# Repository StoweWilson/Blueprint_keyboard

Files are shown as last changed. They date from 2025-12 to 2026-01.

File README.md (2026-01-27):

## What my project is 
My project is a 64% keyboard designed to resemble the layout of an Apple Magic Keyboard, with a few keys rearranged on either side of the PCB. There will be two magnetic pogo pins on either side, which will allow the keypad with identical pogo pins to connect, as well as allowing the keypad to be placed on either side of the keyboard, therefore making it modular. The case takes inspiration from the Worklouder XYZ Work Board.

## Why I made the project
I really like low-profile 60%–65% keyboards but had trouble finding ones that fit my needs. Learning that I had to put my own spin on the idea, I decided to take on the challenge of adding a keypad while keeping it modular, so I could still have the compactness of a 64% keyboard with the ability to have a numpad that does not make it bulky.

## Images

### Keyboard
keyboard sch
Screenshot 2026-01-01 at 11 01 54 PM
Screenshot 2026-01-26 at 7 12 31 PM

### Keypad
keypad pcb
Screenshot 2026-01-01 at 11 03 55 PM
Screenshot 2026-01-26 at 7 13 42 PM

### Render



## BOM
### Keyboard

|Product name|Product Description|Qty|Price|Product Link|
|---|---|---|-----|---|
|ATmega32U4-A|AVR AVR® ATmega Microcontroller IC 8-Bit 16MHz 32KB (16K x 16) FLASH 44-TQFP (10x10)|1|5.29|https://www.digikey.com/en/products/detail/microchip-technology/ATMEGA32U4-AU/1914602|
|16 MHz Crystal|CRYSTAL 3225 16MHZ 20PF 10PPM|1|.18|https://www.digikey.com/en/products/detail/eaton-electronics-division/E3X160201Y08/25656418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|
|USB6B1 ESD Protector|TVS DIODE 5.25VWM 8SOIC|1|.69|https://www.digikey.com/en/products/detail/stmicroelectronics/USB6B1RL/654663|https://www.digikey.com/en/products/detail/amphenol-icc-fci-/10171746-00021LF/24366718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|
|USB-C Receptacle (USB 2.0)|USB C RECEPTACLE R/A SMT 16P G/F|1|.72|https://www.digikey.com/en/products/detail/amphenol-icc-fci-/10171746-00021LF/24366718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|
|10 kΩ|RES 10 OHM 1% 1/8W 0805|2|.11|https://www.digikey.com/en/products/detail/yageo/RC0805FR-1310RL/13694343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|
|22 Ω|RES 22 OHM 1% 1/8W 0805|2|.11|https://www.digikey.com/en/products/detail/yageo/RC0805FR-1322RL/13694339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|
|5.1 kΩ|RES 5.1K OHM 5% 1/8W 0805|2|.10|https://www.digikey.com/en/products/detail/yageo/RC0805JR-075K1L/728338|
|22 pF|22 pF ±5% 50V Ceramic Capacitor C0G, NP0 0603 (1608 Metric)|2|.12|https://www.digikey.com/en/products/detail/kemet/C0603C220J5GACTU/411055|
|1 µF|CAP CER 1UF 6.3V X5R 0402|1|.08|https://www.digikey.com/en/products/detail/samsung-electro-mechanics/CL05A104KA5NNNC/3886701|
|.1uF|0.1 µF ±10% 25V Ceramic Capacitor X5R 0402 (1005 Metric)|4|.08|https://www.digikey.com/en/products/detail/samsung-electro-mechanics/CL05A104KA5NNNC/3886701|
|Diode|DIODE STANDARD 100V 150MA SOD123|64|.11|https://www.digikey.com/en/products/detail/diodes-incorporated/1N4148W-7-F/814371|
|Reset Button|SWITCH TACTILE SPST-NO 0.05A 12V|1|.41|https://www.digikey.ca/en/products/detail/c-k/Y97KT23B2NAFP/9649861|
|Adafruit 5413 Magnetic Connector|four 0.1" spaced contact pogo pins and a right angl|4|2.13|https://www.aliexpress.us/p/shoppingcart/index.html?spm=a2g0o.detail.0.0.2397nvtbnvtbTw|

### Keypad
|Product name|Product Description|Qty|Price|Product Link|
|---|---|---|-----|---|
|XIAO RP2040 SMD|XIAO RP2040 SMD|1|4.68|https://www.digikey.com/en/products/detail/seeed-technology-co-ltd/102010428/14672129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|
|PCF8575DBR I/O Expander|IC XPNDR 400KHZ I2C SMBUS 24SSOP|1|3.58|https://www.digikey.com/en/products/detail/texas-instruments/PCF8575DBR/754551|
|10 kΩ|RES 10 OHM 1% 1/8W 0805|4|.11|https://www.digikey.com/en/products/detail/yageo/RC0805FR-1310RL/13694343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|
|5.1 kΩ|RES 5.1K OHM 5% 1/8W 0805|2|.10|https://www.digikey.com/en/products/detail/yageo/RC0805JR-075K1L/728338|
|Diode|DIODE STANDARD 100V 150MA SOD123|21|.11|https://www.digikey.com/en/products/detail/diodes-incorporated/1N4148W-7-F/814371|
|Adafruit 5413 Magnetic Connector|four 0.1" spaced contact pogo pins and a right angl|4|2.13|https://www.aliexpress.us/p/shoppingcart/index.html?spm=a2g0o.detail.0.0.2397nvtbnvtbTw|

### Notes
- Shipping is not included in any of the prices.
- PCB with shippiing is $59.04 Qty of 5 each can't change.
- I will pay for the keyboard switches with my own money.

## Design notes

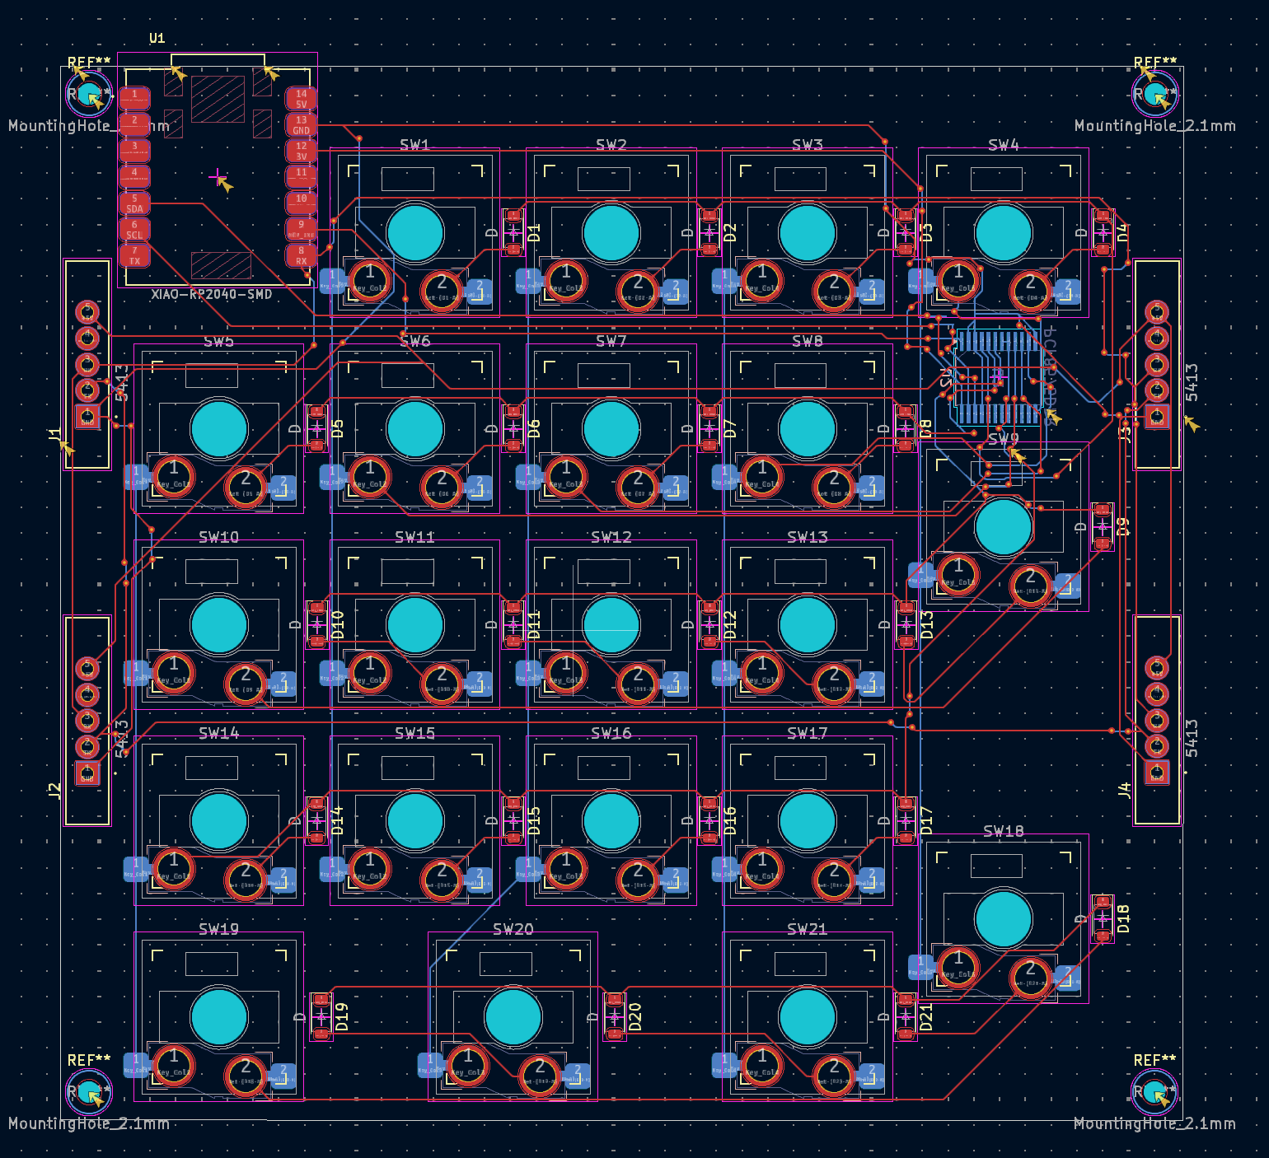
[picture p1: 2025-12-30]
images/keypad pcb.png

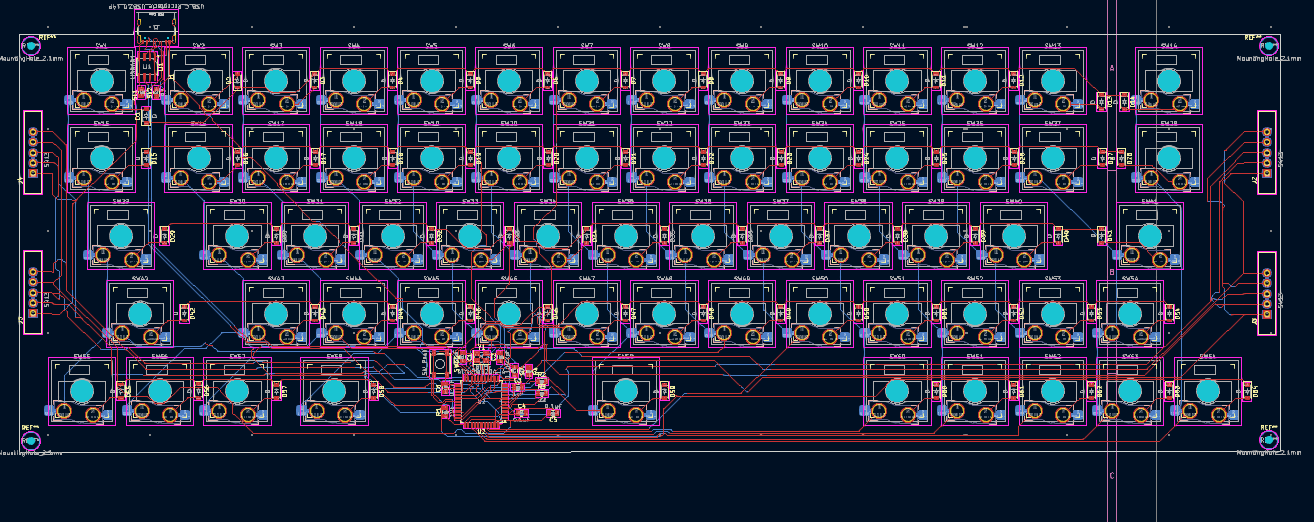
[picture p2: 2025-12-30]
images/keyboard PCB.png

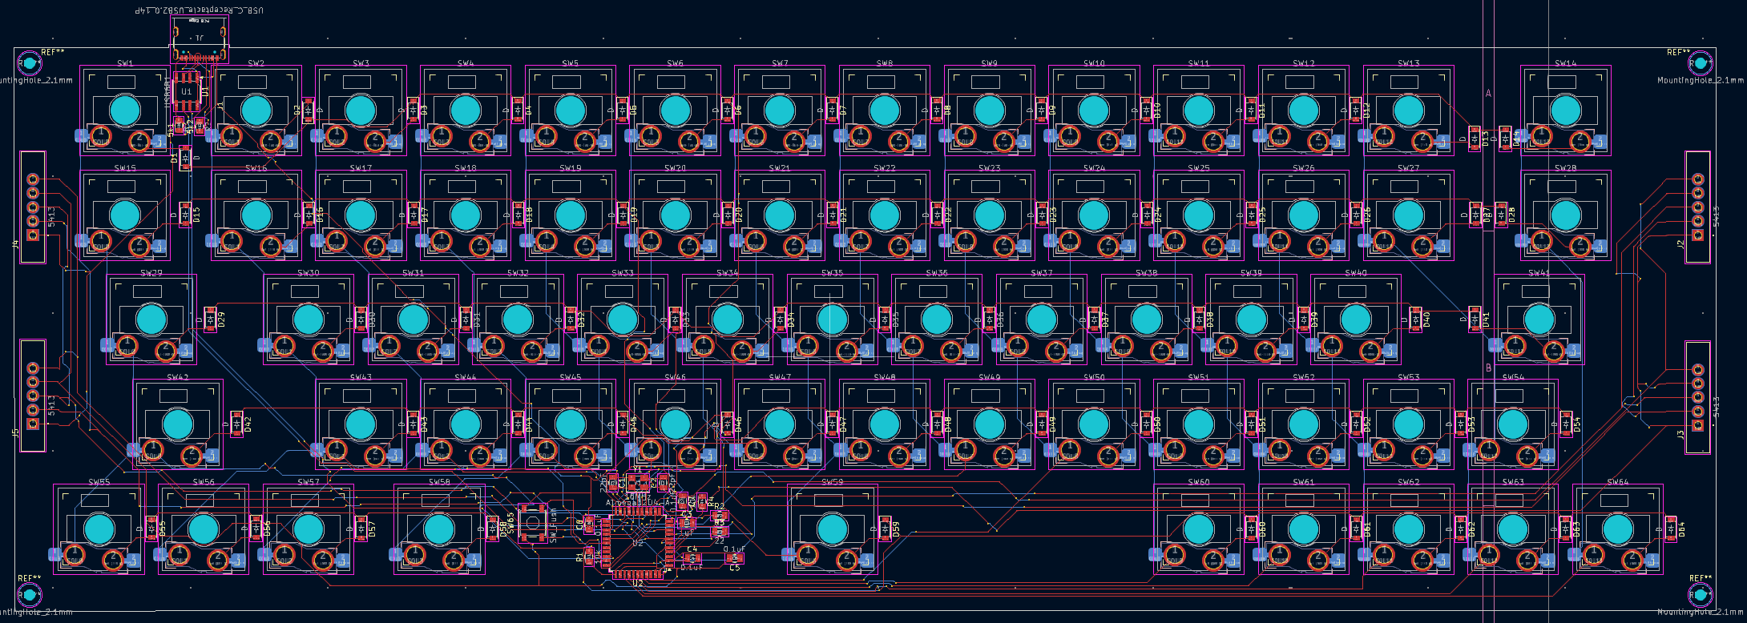
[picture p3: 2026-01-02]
images/Kayboard pcb.png

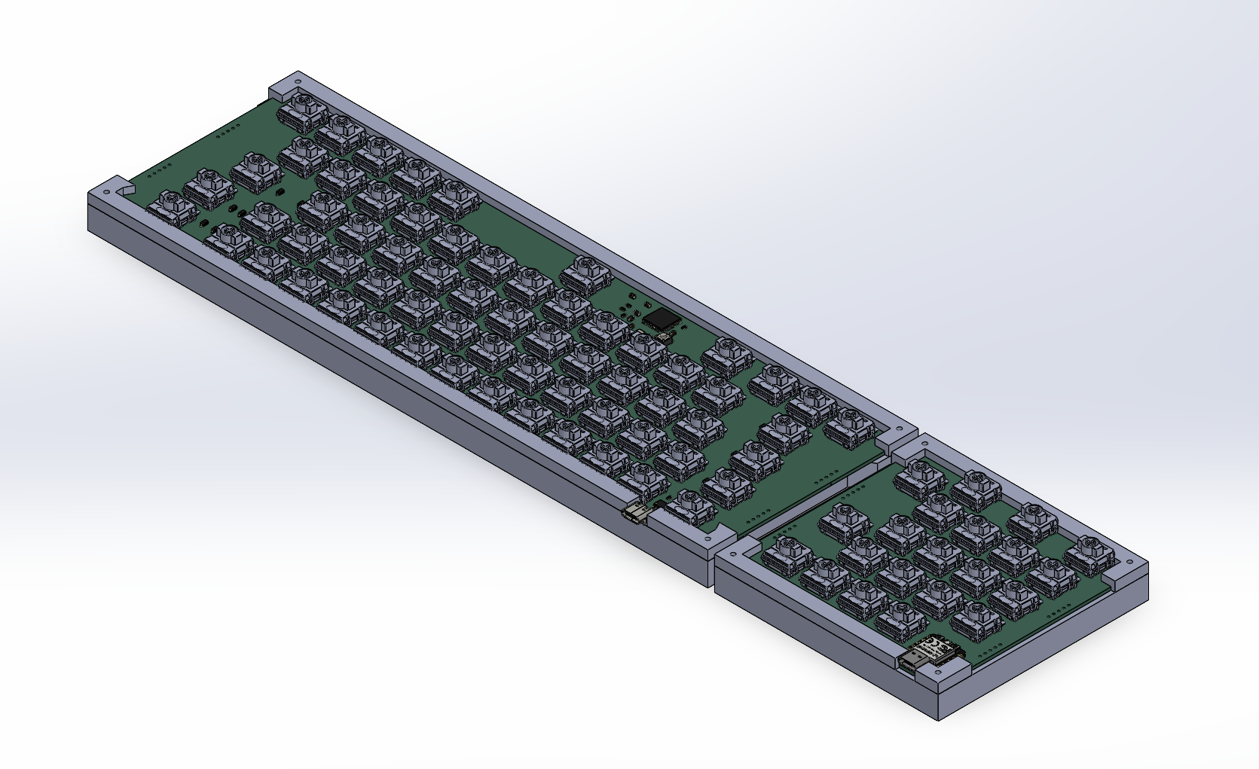
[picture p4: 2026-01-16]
images/keyboardandkeypadcase.png

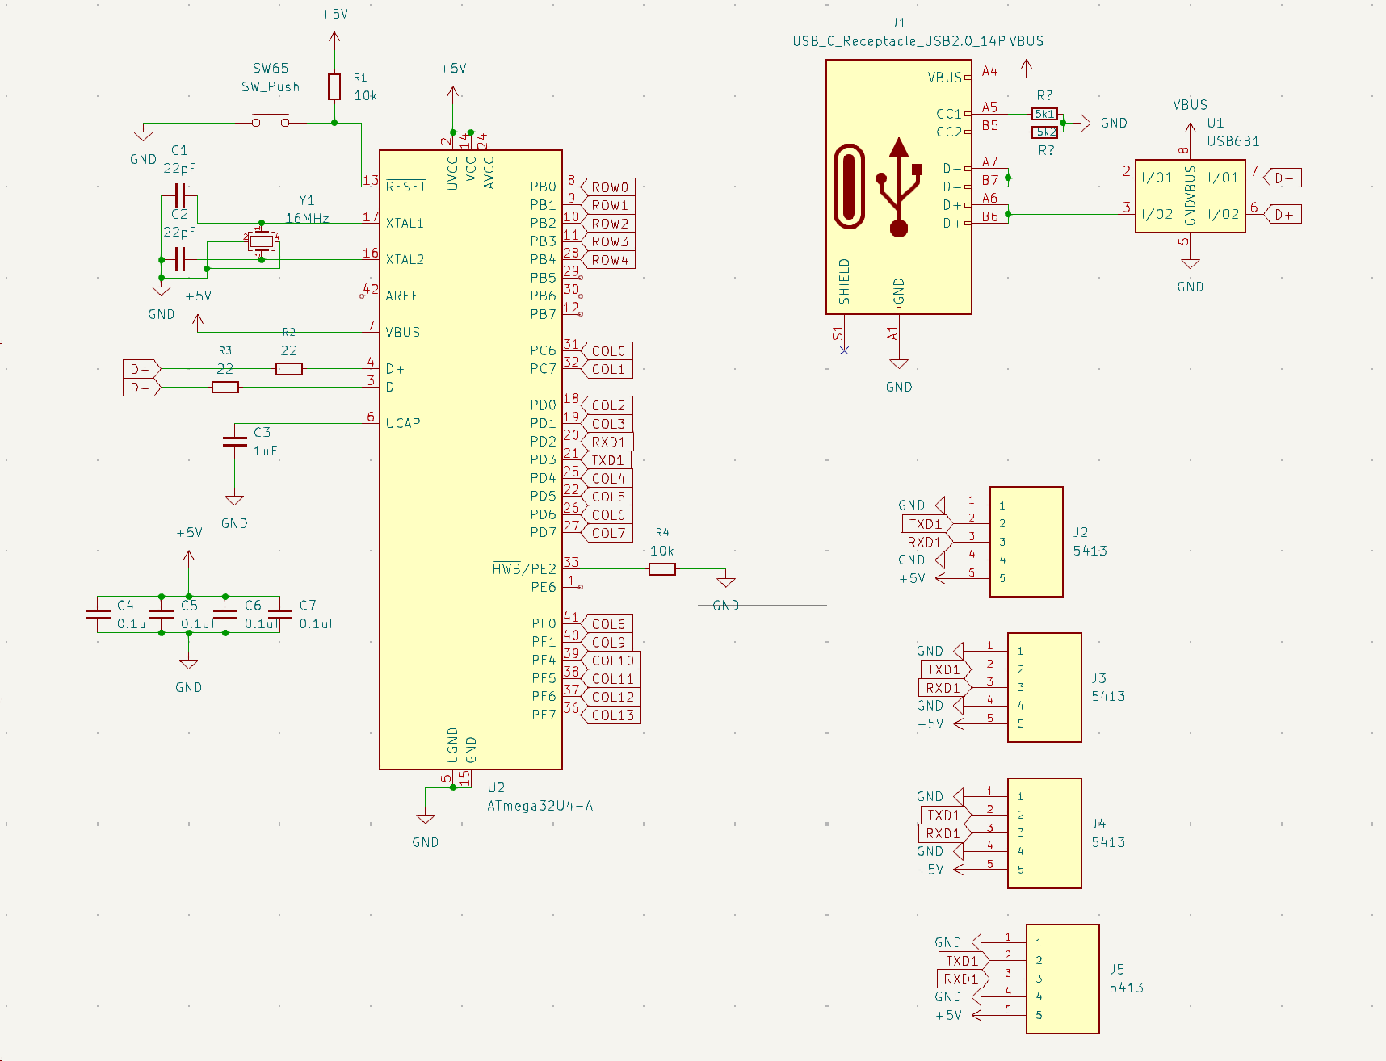
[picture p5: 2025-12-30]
images/keyboard sch.png

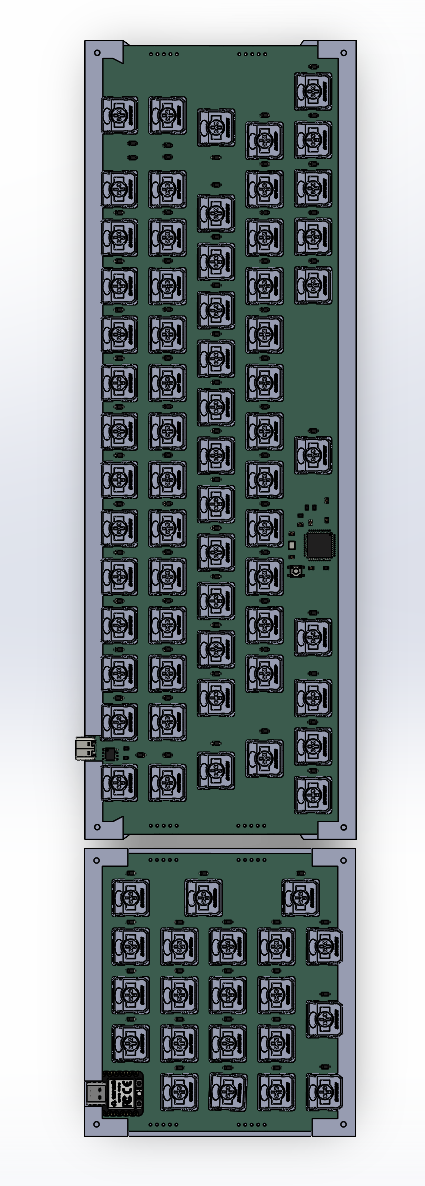
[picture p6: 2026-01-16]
images/topkeybardandkeypad case.png

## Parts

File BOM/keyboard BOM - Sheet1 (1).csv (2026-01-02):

Product name | Product desciption | Qty | Product unit price | Product link | Product running total | with Tax
ATmega32U4-A | AVR AVR® ATmega Microcontroller IC 8-Bit 16MHz 32KB (16K x 16) FLASH 44-TQFP (10x10) | 1 | 5.29 | https://www.digikey.com/en/products/detail/microchip-technology/ATMEGA32U4-AU/1914602 | 5.29 | 5.61
16 MHz Crystal | CRYSTAL 3225 16MHZ 20PF 10PPM | 1 | 0.18 | https://www.digikey.com/en/products/detail/eaton-electronics-division/E3X160201Y08/25656418?gclsrc=aw.ds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 | 0.18 | 0.19
USB6B1 ESD Protector | TVS DIODE 5.25VWM 8SOIC | 1 | 0.69 | https://www.digikey.com/en/products/detail/stmicroelectronics/USB6B1RL/654663 | 0.69 | 0.73
USB-C Receptacle (USB 2.0) | USB C RECEPTACLE R/A SMT 16P G/F | 1 | 0.72 | https://www.digikey.com/en/products/detail/amphenol-icc-fci-/10171746-00021LF/24366718?gclsrc=aw.ds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 | 0.72 | 0.76
10 kΩ | RES 10 OHM 1% 1/8W 0805 | 2 | 0.11 | https://www.digikey.com/en/products/detail/yageo/RC0805FR-1310RL/13694343?gclsrc=aw.ds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 | 0.22 | 0.23
22 Ω | RES 22 OHM 1% 1/8W 0805 | 2 | 0.11 | https://www.digikey.com/en/products/detail/yageo/RC0805FR-1322RL/13694339?gclsrc=aw.ds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 | 0.22 | 0.23
5.1 kΩ | RES 5.1K OHM 5% 1/8W 0805 | 2 | 0.1 | https://www.digikey.com/en/products/detail/yageo/RC0805JR-075K1L/728338 | 0.2 | 0.21
22 pF | 22 pF ±5% 50V Ceramic Capacitor C0G, NP0 0603 (1608 Metric) | 2 | 0.12 | https://www.digikey.com/en/products/detail/kemet/C0603C220J5GACTU/411055 | 0.24 | 0.25
1 µF | CAP CER 1UF 6.3V X5R 0402 | 1 | 0.08 | https://www.digikey.com/en/products/detail/taiyo-yuden/JMK105BJ105KV-F/930583 | 0.08 | 0.08
.1uF | 0.1 µF ±10% 25V Ceramic Capacitor X5R 0402 (1005 Metric) | 4 | 0.08 | https://www.digikey.com/en/products/detail/samsung-electro-mechanics/CL05A104KA5NNNC/3886701 | 0.32 | 0.34
Diode | DIODE STANDARD 100V 150MA SOD123 | 64 | 0.11 | https://www.digikey.com/en/products/detail/diodes-incorporated/1N4148W-7-F/814371 | 7.04 | 7.46
Reset Button | SWITCH TACTILE SPST-NO 0.05A 12V | 1 | 0.41 | https://www.digikey.ca/en/products/detail/c-k/Y97KT23B2NAFP/9649861 | 0.41 | 0.43
Adafruit 5413 Magnetic Connector | four 0.1" spaced contact pogo pins and a right angl | 4 | 6.95 | https://www.adafruit.com/product/5358 | 27.8 | 29.47
 |  |  |  |  | 43.41 | 45.99

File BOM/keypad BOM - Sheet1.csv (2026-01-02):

Product name | Product desciption | Qty | Product unit price | Product link | Product running total | with Tax
XIAO RP2040 SMD | XIAO RP2040 | 1 | 4.68 | https://www.digikey.com/en/products/detail/seeed-technology-co-ltd/102010428/14672129?gclsrc=aw.ds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 | 4.68 | 4.96
PCF8575DBR I/O Expander | IC XPNDR 400KHZ I2C SMBUS 24SSOP | 1 | 3.58 | https://www.digikey.com/en/products/detail/texas-instruments/PCF8575DBR/754551 | 3.58 | 3.79
10 kΩ | RES 10 OHM 1% 1/8W 0805 | 4 | 0.11 | https://www.digikey.com/en/products/detail/yageo/RC0805FR-1310RL/13694343?gclsrc=aw.ds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 | 0.44 | 0.47
5.1 kΩ | RES 5.1K OHM 5% 1/8W 0805 | 2 | 0.1 | https://www.digikey.com/en/products/detail/yageo/RC0805JR-075K1L/728338 | 0.2 | 0.21
Adafruit 5413 Magnetic Connector | four 0.1" spaced contact pogo pins and a right angl | 4 | 6.95 | https://www.adafruit.com/product/5358 | 27.8 | 29.47
Diode | DIODE STANDARD 100V 150MA SOD123 | 21 | 0.11 | https://www.digikey.com/en/products/detail/diodes-incorporated/1N4148W-7-F/814371 | 2.31 | 2.45
 |  |  |  |  | 39.01 | 41.35

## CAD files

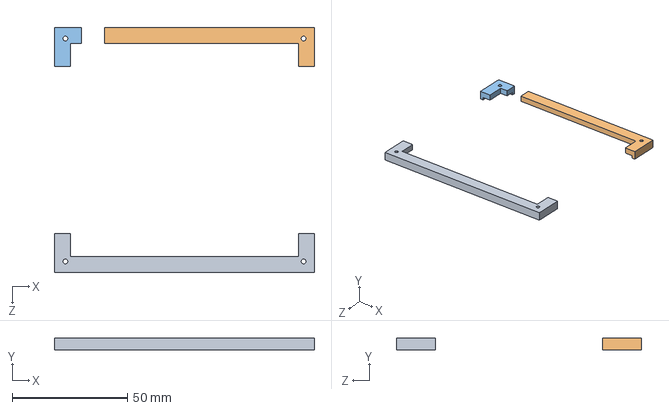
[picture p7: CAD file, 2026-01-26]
CAD/Stowe-Danger-Keypad_Shell-Top.STEP
113.0 x 5.00 x 106.4 mm

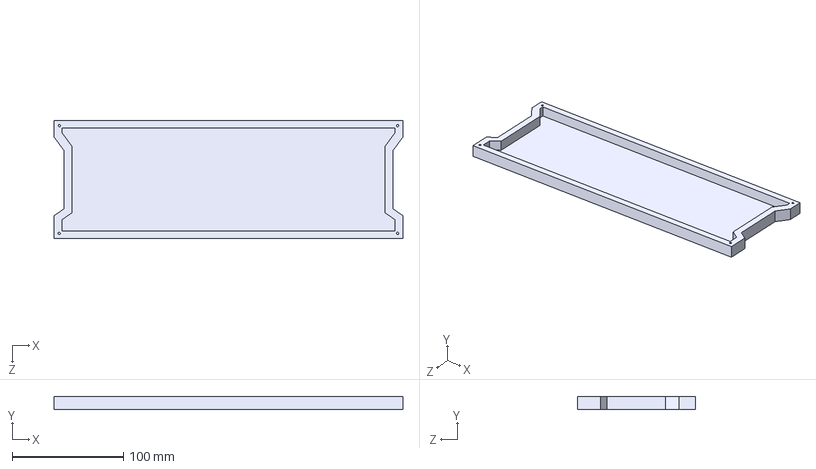
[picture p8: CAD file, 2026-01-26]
CAD/Stowe-Danger-Keyboard_Shell.STEP
313.5 x 11.8 x 106.4 mm

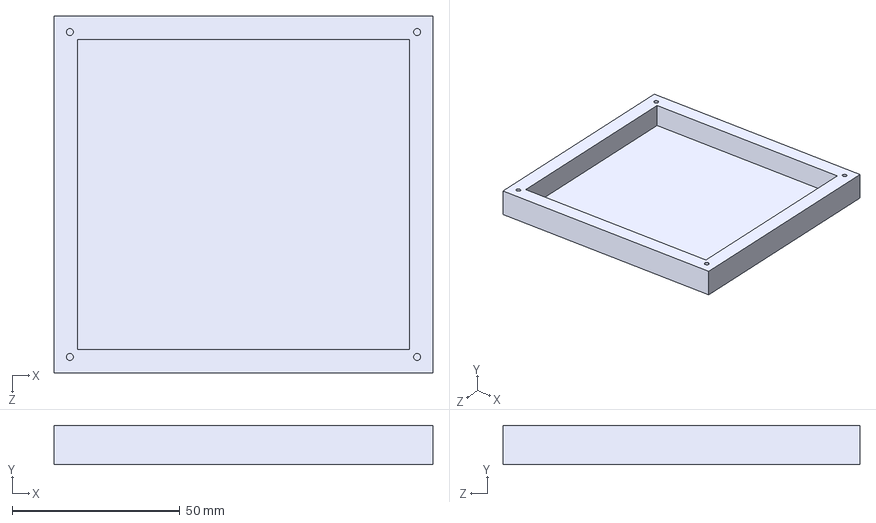
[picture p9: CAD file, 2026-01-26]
CAD/Stowe-Danger-Keypad_Shell.STEP
113.0 x 11.8 x 106.4 mm

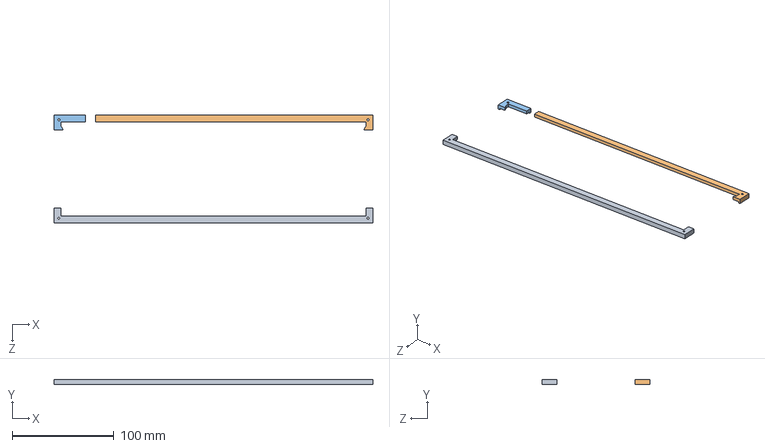
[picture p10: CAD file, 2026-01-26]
CAD/Stowe-Danger-Keyboard_Shell-Top.STEP
313.5 x 5.00 x 106.4 mm

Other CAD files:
CAD/Stowe-Danger-Keyboard_Shell (1).STL
CAD/Stowe-Danger-Keyboard_Shell-Top.STL
CAD/Stowe-Danger-Keypad_Shell-Top.STL
CAD/Stowe-Danger-Keypad_Shell.STL

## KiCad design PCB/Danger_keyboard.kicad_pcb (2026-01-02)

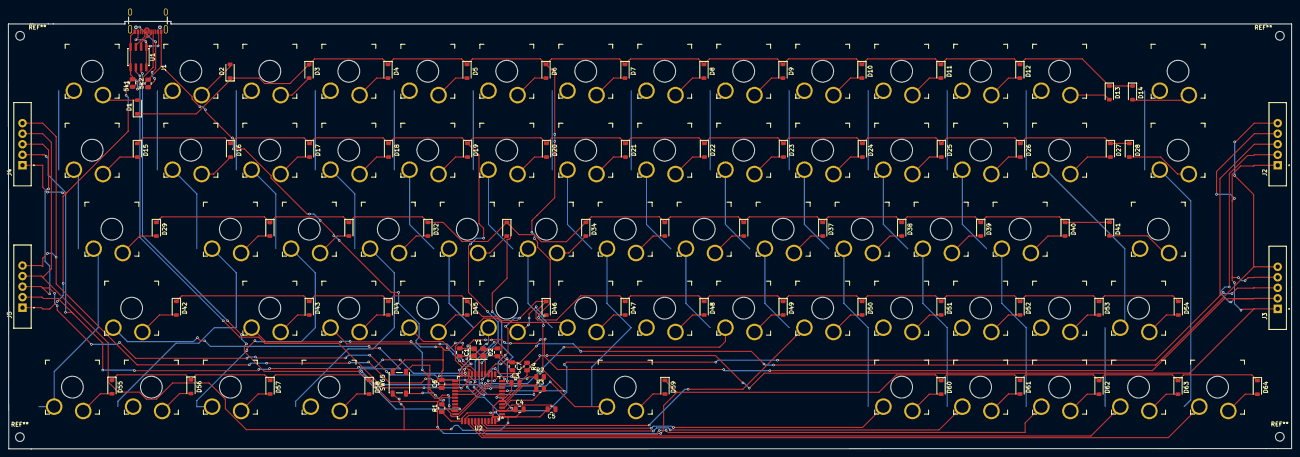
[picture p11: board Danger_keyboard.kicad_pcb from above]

Board: 2 copper layers, 309.5 x 103.1 mm, 150 parts (0 on the bottom side), 101 nets.

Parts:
5k1, 5k2: R?; R_0805_2012Metric
C1, C2: 22pF; C_0805_2012Metric
C3: 1uF; C_0805_2012Metric
C4, C5, C6, C7: 0.1uF; C_0805_2012Metric
D1, D2, D3, D4, D5, D6, D7, D8, D9, D10, D11, D12, D13, D14, D15, D16, D17, D18, D19, D20, D21, D22, D23, D24, D25, D26, D27, D28, D29, D30, D31, D32, D33, D34, D35, D36, D37, D38, D39, D40, D41, D42, D43, D44, D45, D46, D47, D48, D49, D50, D51, D52, D53, D54, D55, D56, D57, D58, D59, D60, D61, D62, D63, D64: D; D_SOD-123
J1: USB_C_Receptacle_USB2.0_14P; USB_C_Receptacle_GCT_USB4105-xx-A_16P_TopMnt_Horizontal
J2, J3, J4, J5: 5413; ADAFRUIT_5413
R1, R4: 10k; R_0805_2012Metric
R2, R3: 22; R_0805_2012Metric
SW1, SW2, SW3, SW4, SW5, SW6, SW7, SW8, SW9, SW10, SW11, SW12, SW13, SW14, SW15, SW16, SW17, SW18, SW19, SW20, SW21, SW22, SW23, SW24, SW25, SW26, SW27, SW28, SW29, SW30, SW31, SW32, SW33, SW34, SW35, SW36, SW37, SW38, SW39, SW40, SW41, SW42, SW43, SW44, SW45, SW46, SW47, SW48, SW49, SW50, SW51, SW52, SW53, SW54, SW55, SW56, SW57, SW58, SW59, SW60, SW61, SW62, SW63, SW64: SW_Push; SW_Gateron_LowProfile_HotSwap_PTH
SW65: SW_Push; SW_SPST_PTS647_Sx38
U1: USB6B1; SOIC-8_3.9x4.9mm_P1.27mm
U2: ATmega32U4-A; TQFP-44_10x10mm_P0.8mm
Y1: 16MHz; Crystal_SMD_3225-4Pin_3.2x2.5mm

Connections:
+5V: C4.1, C5.1, C6.1, C7.1, J2.5, J3.5, J4.5, J5.5, R1.1, U2.2 (UVCC), U2.7 (VBUS), U2.14 (VCC), U2.24 (AVCC), U2.34 (VCC), U2.44 (AVCC)
COL0: SW1.1, SW15.1, SW29.1, SW42.1, SW55.1, U2.31 (PC6)
COL1: SW2.1, SW16.1, SW30.1, SW43.1, SW56.1, U2.32 (PC7)
COL2: SW3.1, SW17.1, SW31.1, SW44.1, SW57.1, U2.18 (PD0)
COL3: SW4.1, SW18.1, SW32.1, SW45.1, SW58.1, U2.19 (PD1)
COL4: SW5.1, SW19.1, SW33.1, SW46.1, U2.25 (PD4)
COL5: SW6.1, SW20.1, SW34.1, SW47.1, U2.22 (PD5)
COL6: SW7.1, SW21.1, SW35.1, SW48.1, SW59.1, U2.26 (PD6)
COL7: SW8.1, SW22.1, SW36.1, SW49.1, U2.27 (PD7)
COL8: SW9.1, SW23.1, SW37.1, SW50.1, U2.41 (PF0)
COL9: SW10.1, SW24.1, SW38.1, SW51.1, SW60.1, U2.40 (PF1)
COL10: SW11.1, SW25.1, SW39.1, SW52.1, SW61.1, U2.39 (PF4)
COL11: SW12.1, SW26.1, SW40.1, SW53.1, SW62.1, U2.38 (PF5)
COL12: SW13.1, SW27.1, SW41.1, SW54.1, SW63.1, U2.37 (PF6)
COL13: SW14.1, SW28.1, SW64.1, U2.36 (PF7)
D+: R2.1, U1.6 (I/O2)
D-: R3.1, U1.7 (I/O1)
GND: 5k1.2, 5k2.2, C1.1, C2.1, C3.2, C4.2, C5.2, C6.2, C7.2, J1.A1 (GND), J1.A12 (GND), J1.B1 (GND), J1.B12 (GND), J2.1, J2.4, J3.1, J3.4, J4.1, J4.4, J5.1, J5.4, R4.2, SW65.1, U1.4 (GND), U1.5 (GND), U2.5 (UGND), U2.15 (GND), U2.23 (GND), U2.35 (GND), U2.43 (GND), Y1.2, Y1.4
unnamed: D1.2 (A), SW1.2
unnamed: D2.2 (A), SW2.2
unnamed: D3.2 (A), SW3.2
unnamed: D4.2 (A), SW4.2
unnamed: D5.2 (A), SW5.2
unnamed: D6.2 (A), SW6.2
unnamed: D7.2 (A), SW7.2
unnamed: D8.2 (A), SW8.2
unnamed: D9.2 (A), SW9.2
unnamed: D10.2 (A), SW10.2
unnamed: D11.2 (A), SW11.2
unnamed: D12.2 (A), SW12.2
unnamed: D13.2 (A), SW13.2
unnamed: D14.2 (A), SW14.2
unnamed: D15.2 (A), SW15.2
unnamed: D16.2 (A), SW16.2
unnamed: D17.2 (A), SW17.2
unnamed: D18.2 (A), SW18.2
unnamed: D19.2 (A), SW19.2
unnamed: D20.2 (A), SW20.2
unnamed: D21.2 (A), SW21.2
unnamed: D22.2 (A), SW22.2
unnamed: D23.2 (A), SW23.2
unnamed: D24.2 (A), SW24.2
unnamed: D25.2 (A), SW25.2
unnamed: D26.2 (A), SW26.2
unnamed: D27.2 (A), SW27.2
unnamed: D28.2 (A), SW28.2
unnamed: D29.2 (A), SW29.2
unnamed: D30.2 (A), SW30.2
unnamed: D31.2 (A), SW31.2
unnamed: D32.2 (A), SW32.2
unnamed: D33.2 (A), SW33.2
unnamed: D34.2 (A), SW34.2
unnamed: D35.2 (A), SW35.2
unnamed: D36.2 (A), SW36.2
unnamed: D37.2 (A), SW37.2
unnamed: D38.2 (A), SW38.2
unnamed: D39.2 (A), SW39.2
unnamed: D40.2 (A), SW40.2
unnamed: D41.2 (A), SW41.2
unnamed: D42.2 (A), SW42.2
unnamed: D43.2 (A), SW43.2
unnamed: D44.2 (A), SW44.2
unnamed: D45.2 (A), SW45.2
unnamed: D46.2 (A), SW46.2
unnamed: D47.2 (A), SW47.2
unnamed: D48.2 (A), SW48.2
unnamed: D49.2 (A), SW49.2
unnamed: D50.2 (A), SW50.2
unnamed: D51.2 (A), SW51.2
unnamed: D52.2 (A), SW52.2
unnamed: D53.2 (A), SW53.2
unnamed: D54.2 (A), SW54.2
unnamed: D55.2 (A), SW55.2
unnamed: D56.2 (A), SW56.2
unnamed: D57.2 (A), SW57.2
unnamed: D58.2 (A), SW58.2
unnamed: D59.2 (A), SW59.2
unnamed: D60.2 (A), SW60.2
unnamed: D61.2 (A), SW61.2
unnamed: D62.2 (A), SW62.2
unnamed: D63.2 (A), SW63.2
unnamed: D64.2 (A), SW64.2
unnamed: 5k1.1, J1.A5 (CC1)
unnamed: 5k2.1, J1.B5 (CC2)
unnamed: J1.A6 (D+), J1.B6 (D+), U1.3 (I/O2)
unnamed: J1.A7 (D-), J1.B7 (D-), U1.2 (I/O1)
unnamed: R2.2, U2.4 (D+)
unnamed: R3.2, U2.3 (D-)
unnamed: C3.1, U2.6 (UCAP)
unnamed: C1.2, U2.17 (XTAL1), Y1.1
unnamed: C2.2, U2.16 (XTAL2), Y1.3
unnamed: R4.1, U2.33 (~HWB/PE2)
unnamed: R1.2, SW65.2, U2.13 (~RESET)
ROW0: D1.1 (K), D2.1 (K), D3.1 (K), D4.1 (K), D5.1 (K), D6.1 (K), D7.1 (K), D8.1 (K), D9.1 (K), D10.1 (K), D11.1 (K), D12.1 (K), D13.1 (K), D14.1 (K), U2.8 (PB0)
ROW1: D15.1 (K), D16.1 (K), D17.1 (K), D18.1 (K), D19.1 (K), D20.1 (K), D21.1 (K), D22.1 (K), D23.1 (K), D24.1 (K), D25.1 (K), D26.1 (K), D27.1 (K), D28.1 (K), U2.9 (PB1)
ROW2: D29.1 (K), D30.1 (K), D31.1 (K), D32.1 (K), D33.1 (K), D34.1 (K), D35.1 (K), D36.1 (K), D37.1 (K), D38.1 (K), D39.1 (K), D40.1 (K), D41.1 (K), U2.10 (PB2)
ROW3: D42.1 (K), D43.1 (K), D44.1 (K), D45.1 (K), D46.1 (K), D47.1 (K), D48.1 (K), D49.1 (K), D50.1 (K), D51.1 (K), D52.1 (K), D53.1 (K), D54.1 (K), U2.11 (PB3)
ROW4: D55.1 (K), D56.1 (K), D57.1 (K), D58.1 (K), D59.1 (K), D60.1 (K), D61.1 (K), D62.1 (K), D63.1 (K), D64.1 (K), U2.28 (PB4)
RXD1: J2.3, J3.3, J4.3, J5.3, U2.20 (PD2)
TXD1: J2.2, J3.2, J4.2, J5.2, U2.21 (PD3)
VBUS: J1.A4 (VBUS), J1.A9 (VBUS), J1.B4 (VBUS), J1.B9 (VBUS), U1.1 (VBUS), U1.8 (VBUS)

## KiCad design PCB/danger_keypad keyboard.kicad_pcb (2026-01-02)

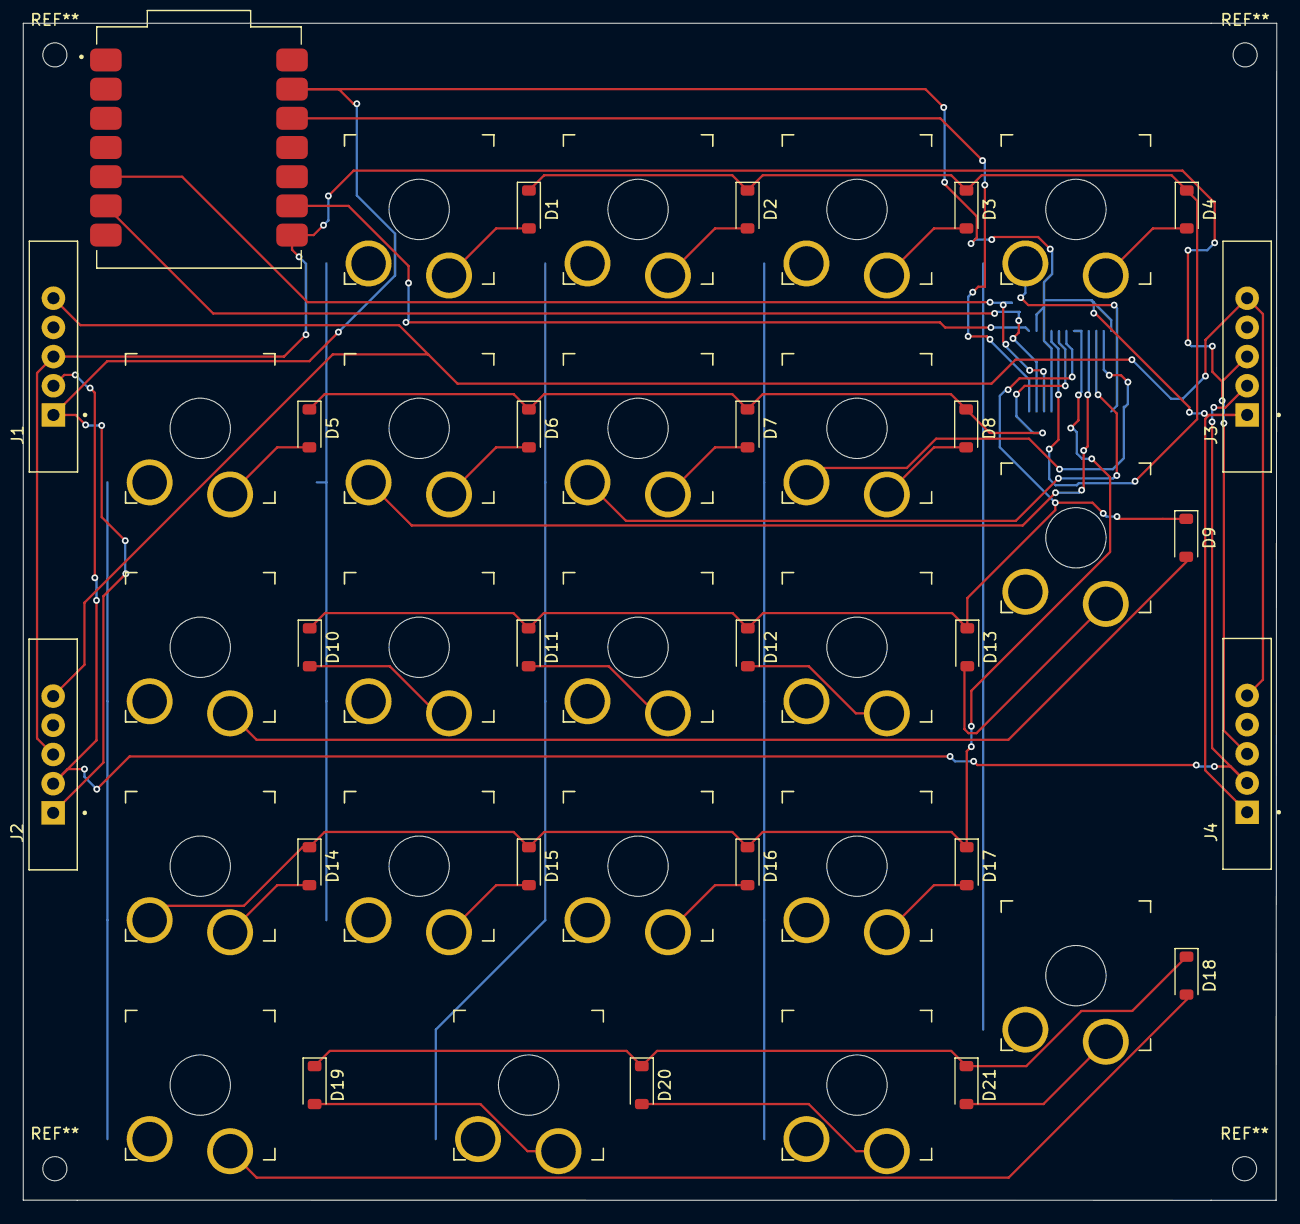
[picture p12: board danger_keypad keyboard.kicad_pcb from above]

Board: 2 copper layers, 109.1 x 102.4 mm, 48 parts (1 on the bottom side), 38 nets.

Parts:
D1, D2, D3, D4, D5, D6, D7, D8, D9, D10, D11, D12, D13, D14, D15, D16, D17, D18, D19, D20, D21: D; D_SOD-123
J1, J2, J3, J4: 5413; ADAFRUIT_5413
SW1, SW2, SW3, SW4, SW5, SW6, SW7, SW8, SW9, SW10, SW11, SW12, SW13, SW14, SW15, SW16, SW17, SW18, SW19, SW20, SW21: SW_Push; SW_Gateron_LowProfile_HotSwap_PTH
U1: XIAO-RP2040-SMD; MODULE_102010428
U2: PCF8575DBR; SSOP-24_5.3x8.2mm_P0.65mm

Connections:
3V: U1.12 (3V3), U2.24 (VCC)
+5V: J1.5, J2.5, J3.5, J4.5
GND: J1.1, J2.1, J3.1, J4.1, U1.13 (GND), U2.2 (A1), U2.3 (A2), U2.12 (GND), U2.21 (A0)
Key_Col1: D14.1 (K), D15.1 (K), D16.1 (K), D17.1 (K), SW5.1, SW10.1, SW14.1, SW19.1, U2.7 (P3), U2.8 (P4)
Key_Col2: SW1.1, SW6.1, SW11.1, SW15.1, U2.9 (P5)
Key_Col3: SW2.1, SW7.1, SW12.1, SW16.1, SW20.1, U2.10 (P6)
Key_Col4: SW3.1, SW8.1, SW13.1, SW17.1, SW21.1, U2.11 (P7)
Key_Col5: SW4.1, SW9.1, SW18.1, U2.13 (P10)
Key_Row1: D1.1 (K), D2.1 (K), D3.1 (K), D4.1 (K), U2.4 (P0)
Key_Row2: D5.1 (K), D6.1 (K), D7.1 (K), D8.1 (K), U2.5 (P1)
Key_Row3: D9.1 (K), D10.1 (K), D11.1 (K), D12.1 (K), D13.1 (K), U2.6 (P2)
Key_Row5: D18.1 (K), D19.1 (K), D20.1 (K), D21.1 (K)
MCP_INT: U1.9 (GPIO2_D8_SCK), U2.1 (~INT)
unnamed: D1.2 (A), SW1.2
unnamed: D2.2 (A), SW2.2
unnamed: D3.2 (A), SW3.2
unnamed: D4.2 (A), SW4.2
unnamed: D5.2 (A), SW5.2
unnamed: D6.2 (A), SW6.2
unnamed: D7.2 (A), SW7.2
unnamed: D8.2 (A), SW8.2
unnamed: D9.2 (A), SW10.2
unnamed: D10.2 (A), SW11.2
unnamed: D11.2 (A), SW12.2
unnamed: D12.2 (A), SW13.2
unnamed: D13.2 (A), SW9.2
unnamed: D14.2 (A), SW14.2
unnamed: D15.2 (A), SW15.2
unnamed: D16.2 (A), SW16.2
unnamed: D17.2 (A), SW17.2
unnamed: D18.2 (A), SW19.2
unnamed: D19.2 (A), SW20.2
unnamed: D20.2 (A), SW21.2
unnamed: D21.2 (A), SW18.2
RX: J1.3, J2.3, J3.3, J4.3, U1.8 (GPIO1_D7_CSn_RX)
SCL: U1.6 (GPIO7_D5_SCL), U2.23 (SDA)
SDA: U1.5 (GPIO6_D4_SDA), U2.22 (SCL)
TK: J1.2, J2.2, J3.2, J4.2

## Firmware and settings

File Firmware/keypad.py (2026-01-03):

#include <Wire.h>
#include <Keyboard.h>

#define PCF_ADDR 0x20

#define ROWS 5
#define COLS 5

const uint8_t rowBits[ROWS] = {0, 1, 2, 3, 4};
const uint8_t colBits[COLS] = {5, 6, 7, 8, 9};

const uint8_t keymap[5][5] = {
  {KEY_F13,      'o',        't',        's',        'x'       }, 
  {KEY_F14,      KEY_NUM_LOCK, '/',      '*',        '-'       },  
  {KEY_F15,      '7',        '8',        '9',        '+'       },  
  {KEY_F16,      '4',        '5',        '6',        KEY_RETURN},  
  {KEY_F17,      '1',        '2',        '3',        '.'       }   
};

bool stable[ROWS][COLS];
bool lastStable[ROWS][COLS];
uint32_t lastChange[ROWS][COLS];

void pcfWrite(uint16_t v) {
  Wire.beginTransmission(PCF_ADDR);
  Wire.write(v & 0xFF);
  Wire.write(v >> 8);
  Wire.endTransmission();
}

uint16_t pcfRead() {
  Wire.requestFrom(PCF_ADDR, 2);
  uint16_t v = Wire.read();
  v |= Wire.read() << 8;
  return v;
}

void driveRow(int r) {
  uint16_t v = 0xFFFF;
  v &= ~(1 << rowBits[r]);
  pcfWrite(v);
}

bool readKey(int r, int c) {
  return !(pcfRead() & (1 << colBits[c]));
}

void setup() {
  Wire.begin();
  Wire.setClock(400000);
  pcfWrite(0xFFFF);
  Keyboard.begin();
  uint32_t t = millis();
  for (int r = 0; r < ROWS; r++)
    for (int c = 0; c < COLS; c++)
      stable[r][c] = lastStable[r][c] = false, lastChange[r][c] = t;
}

void loop() {
  static uint32_t lastScan = 0;
  uint32_t now = millis();
  if (now - lastScan < 2) return;
  lastScan = now;

  for (int r = 0; r < ROWS; r++) {
    driveRow(r);
    delayMicroseconds(250);

    for (int c = 0; c < COLS; c++) {
      bool raw = readKey(r, c);
      if (raw != stable[r][c]) {
        stable[r][c] = raw;
        lastChange[r][c] = now;
      }
      if (now - lastChange[r][c] > 10) {
        if (stable[r][c] != lastStable[r][c]) {
          lastStable[r][c] = stable[r][c];
          if (stable[r][c]) Keyboard.press(keymap[r][c]);
          else Keyboard.release(keymap[r][c]);
        }
      }
    }
    pcfWrite(0xFFFF);
  }
}

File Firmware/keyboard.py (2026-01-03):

import board
import busio
import time

from kmk.kmk_keyboard import KMKKeyboard
from kmk.matrix import DiodeOrientation
from kmk.keys import KC
from kmk.modules.layers import Layers

from kmk.extensions.ioexpander import IOExpander
from kmk.extensions.ioexpander.mcp230xx import MCP23017

keyboard = KMKKeyboard()
keyboard.modules.append(Layers())

keyboard.diode_orientation = DiodeOrientation.COLUMNS

keyboard.col_pins = (
    board.GP0, board.GP1, board.GP2, board.GP3, board.GP4, board.GP5, board.GP6,
    board.GP7, board.GP8, board.GP9, board.GP10, board.GP11, board.GP12
)
keyboard.row_pins = (board.GP13, board.GP14, board.GP15, board.GP16)

MCP_ADDR = 0x20
i2c = busio.I2C(board.SCL, board.SDA)

def i2c_has(addr: int) -> bool:
    t0 = time.monotonic()
    while not i2c.try_lock():
        if time.monotonic() - t0 > 1.0:
            return False
        time.sleep(0.01)
    try:
        return addr in i2c.scan()
    finally:
        i2c.unlock()

pad_attached = False
if i2c_has(MCP_ADDR):
    try:
        mcp = MCP23017(i2c=i2c, i2c_addr=MCP_ADDR)
        exp = IOExpander(mcp)
        exp.col_pins = (0, 1, 2, 3, 4)
        exp.row_pins = (8, 9, 10, 11, 12)
        keyboard.extensions.append(exp)
        pad_attached = True
    except Exception:
        pad_attached = False

MAIN_L0 = [
    KC.ESC, KC.N1, KC.N2, KC.N3, KC.N4, KC.N5, KC.N6, KC.N7, KC.N8, KC.N9, KC.N0, KC.MINS, KC.EQL,
    KC.TAB, KC.Q,  KC.W,  KC.E,  KC.R,  KC.T,  KC.Y,  KC.U,  KC.I,  KC.O,  KC.P,  KC.LBRC, KC.RBRC,
    KC.CAPS,KC.A,  KC.S,  KC.D,  KC.F,  KC.G,  KC.H,  KC.J,  KC.K,  KC.L,  KC.SCLN,KC.QUOT,KC.BSLS,
    KC.LSFT,KC.Z,  KC.X,  KC.C,  KC.V,  KC.B,  KC.N,  KC.M,  KC.COMM,KC.DOT, KC.SLSH, KC.MO(1), KC.ENT,
]

MAIN_L1 = [
    KC.GRV, KC.F1, KC.F2, KC.F3, KC.F4, KC.F5, KC.F6, KC.F7, KC.F8, KC.F9, KC.F10, KC.F11, KC.F12,
    KC.TRNS,KC.EXLM,KC.AT, KC.HASH,KC.DLR,KC.PERC,KC.CIRC,KC.AMPR,KC.ASTR,KC.LPRN,KC.RPRN,KC.UNDS,KC.PLUS,
    KC.TRNS,KC.LEFT,KC.DOWN,KC.UP,  KC.RGHT,KC.PGUP,KC.HOME,KC.END, KC.INS, KC.DEL, KC.TRNS,KC.TRNS,KC.TRNS,
    KC.TRNS,KC.MPRV,KC.MPLY,KC.MNXT,KC.VOLD,KC.VOLU,KC.MUTE,KC.BSPC,KC.TRNS,KC.TRNS,KC.TRNS,KC.TRNS,KC.TRNS,
]

PAD_L0 = [
    KC.NLCK, KC.PSLS, KC.PAST, KC.PMNS, KC.PGUP,
    KC.P7,   KC.P8,   KC.P9,   KC.PPLS, KC.HOME,
    KC.P4,   KC.P5,   KC.P6,   KC.PPLS, KC.END,
    KC.P1,   KC.P2,   KC.P3,   KC.PENT, KC.PGDN,
    KC.P0,   KC.PDOT, KC.PCMM, KC.MUTE, KC.DEL,
]

PAD_L1 = [
    KC.MPLY, KC.MPRV, KC.MNXT, KC.VOLD, KC.VOLU,
    KC.TRNS, KC.TRNS, KC.TRNS, KC.VOLU, KC.TRNS,
    KC.TRNS, KC.TRNS, KC.TRNS, KC.VOLU, KC.TRNS,
    KC.TRNS, KC.TRNS, KC.TRNS, KC.TRNS, KC.TRNS,
    KC.TRNS, KC.TRNS, KC.TRNS, KC.TRNS, KC.TRNS,
]

keyboard.keymap = [
    MAIN_L0 + (PAD_L0 if pad_attached else []),
    MAIN_L1 + (PAD_L1 if pad_attached else []),
]

keyboard.go()

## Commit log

2025-12-14 My pcb stuff
    hopefully all of it
    [Danger_keyboard.kicad_pcb, Danger_keyboard.kicad_sch, keypad.kicad_pcb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]
2025-12-14 Create PCB
2025-12-28 Add Bill of Materials for keyboard PCBs
    Added a Bill of Materials (BOM) section with details for the Main Keyboard PCB and Keypad/Expansion PCB, including components, quantities, and links to datasheets.
2025-12-29 Add prices and links to BOM in README.md
    Updated the Bill of Materials (BOM) with prices and links for components.
2025-12-29 Update Reset Button price and link in README
    Updated the price and link for the Reset Button.
2025-12-29 Add PCB pricing and links to README
2025-12-29 Fix formatting in PCB reference table
2025-12-29 Update README with PCB details and shipping note
    Added PCB entry and shipping note to the README.
2025-12-29 Update PCB pricing details in README
    Correct the pricing information for PCB with shipping.
2025-12-30 Update C4–C7 price and supplier link
    Updated the price and link for capacitor C4–C7.
2026-01-02 Revise project overview and BOM details
    Updated project description and added images for keyboard and keypad. Revised BOM details and notes.
2026-01-02 move in right places
    [keyboard BOM - Sheet1.csv, keypad BOM - Sheet1.csv]
2026-01-02 messed up the BOM fixed it
    [keyboard BOM - Sheet1 (1).csv]
2026-01-02 Add 0.1 µF capacitor to component list in README
2026-01-02 new files making sure everything is up to date
    [Danger_keyboard.kicad_pcb, Danger_keyboard.kicad_sch, danger_keypad keyboard.kicad_pcb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]
2026-01-03 Revise prices and links in README BOM
    Updated product prices and links in BOM section.
